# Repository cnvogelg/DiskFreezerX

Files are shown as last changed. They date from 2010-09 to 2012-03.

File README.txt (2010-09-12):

The DiskFreezerX Project
------------------------

Introduction
------------

The DiskFreezerX is a tool suite that allows to capture bit cell exact
information from a floppy disk. This approach samples disk information at the
lowest possible level and therefore preserves as much information as possible.

This project is heavily inspired by the ideas presented in the Cyclone 20 [1]
and KryoFlux [2] projects. We share the hardware platform (AT91SAM7x) for
connecting the disk drive and doing the low level sampling of the disk data.
However, all the software in this project was written from scratch.
Furthermore, the host hardware in DiskFreezerX is a beagle board that is
connected via SPI to the AT91SAM7x and not a PC connected via USB.

The goal of the DiskFreezerX project is to provide a modular tool set for
sampling disk information in a versatile way. We want to provide a full open
source solution to exact bit cell level disk archiving that supports lots of
platforms and devices. We start of with a working sample system running on a
beagle board and a SAM7x board and hope to add new supported HW platforms in
the near future.

Currently, the project is in no way an end user project, i.e. you cannot
simply buy some HW and off you go. It is rather a hacker project for you
technically skilled folks out there that know how to handle the HW stuff
described here... So you have been warned ;)

And now have fun!

Chris Vogelgsang aka. lallafa
<chris@vogelgsang.org>

[1] http://eab.abime.net/showthread.php?t=40959
    https://docs.google.com/Doc?id=dgddtc7_102gbzr2mgr&hl=en
[2] http://www.kryoflux.com/

Overview
--------

A DiskFreezerX system consists of the following components:

* A _Sampler_ is a hardware device that connects to the floppy drive, controls
  the floppy and samples the disk information. The sampling process is very
  time critical and therefore has a direct bare-metal implementation on a
  microcontroller. The sampled data contains large amounts of information and
  therefore. The "dfx-sampler" is the firmware running on a sampler. 

* A _Capture_ program that runs on a host system and is connected to the
  Sampler device. It does control the floppy drive (enable motor, step track,
  ...) and receives the bit cells sampled from the sampler. The capture
  program "dfx-capture" stores the sampled tracks for further processing

* _Anaylzer_ programs read the captured data and do the reconstruction of the
  bit information stored on disk and then the high level structures found
  there, e.g. disk formats of operating systems. As a result of analysis you
  either get lots information about the data found on the disk or you can
  directly derive disk images that can be used in emulators. The analyzers
  are currently written in Python and called with "dfx-analyzer".

Current System
--------------

The current reference platform consists of the following components:

* The Sampler is a AT91SAM7x board that directly connects to the floppy drive.
  The dfx-sampler firmware running there is written in C using only bare-metal
  (i.e. register) access to the device. The communication with the capture
  host is done via an SPI link. The SPI link runs at 3 MBit/s and the sampler
  is the slave device. Both the control commands and the sampled track data
  are transferred along this link.

* The capture host is a Beagle Board clone called IGEP v2 [3]. This board has
  an OMAP3 Cortex A8 ARM processor at 720 MHz and runs Poky Linux [4]. The
  board has an extension connector that provides an SPI channel. With a level
  converter attached (1.8V to 3.3V) the SPI can be directly connected to the
  SAM7x board. The dfx-capture software is written for the Linux spidev
  user-level SPI programming interface and requires a patched Linux kernel
  that enables the SPI device on the external connector. The capture software
  currently writes sampled raw tracks to one file per track. A disk is sampled
  as a directory of raw track files.

* The analyzer software is written in Python and runs on any system with a
  Python interpreter available. The analyzer handles single raw tracks and
  decodes them into blocks found on this track. A disk image is currently
  build by concatenating track blocks together. In future the anaylzer
  software will be extended into a Python class library with lots of helper
  classes for doing track analysis.

[3] http://www.igep-platform.com/index.php?option=com_content&view=article&id=46&Itemid=55
[4] http://labs.igep.es/index.php/How_to_setup_a_development_environment

Getting Started
---------------

More documentation of this project is located in the "doc" directory.
You'll find there:

EOF

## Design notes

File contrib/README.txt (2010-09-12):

igep_v2_spi_patch-2.6.33.6.diff

  This patch has to be applied to the IGEP v2 Kernel 2.6.33.6
  available at http://git.igep.es/?p=pub/scm/linux-omap-2.6.git;a=summary

  Have a look at
  http://labs.igep.es/index.php/Getting_started_with_IGEP_v2_board
  for more information about how to setup an own kernel for the board.

EOF

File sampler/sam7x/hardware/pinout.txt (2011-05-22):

DiskFreezerX SAM7x256 Pinout
----------------------------

PA0   OUT   floppy: WRITE DATA         (FD 22)
PA1   IN    floppy: WRITE_PROTECT      (FD 28)
PA2   OUT   floppy: DENSITY SEL        (FD  2)
PA3   OUT   SPI: WIZNET /CS
PA4   OUT   SPI: RTC /CS
PA5   OUT   SPIRAM: A0
PA6   OUT   SPIRAM: A1
PA7   OUT   SPIRAM: A2
PA8   OUT   SPIRAM: /CS
PA9   IN    floppy: TRACK 0            (FD  9)
PA10  OUT   floppy: SELECT 0           (FD 14)
PA11  OUT   SD CARD: /CS
PA12  IN    SPI: MISO
PA13  OUT   SPI: MOSI
PA14  OUT   SPI: CLK
PA15  IN    SD CARD: CARD DETECT

PA16  OUT   (EXTRA /CS)
PA17  OUT   LED 1
PA18  OUT   LED 2
PA19  OUT   floppy: MOTOR 0            (FD 10)
PA20  IN    WIZNET /IRQ
PA21  IN    RXD1 (Serial)
PA22  OUT   TXD1 (Serial)
PA23  IN    BUTTON 1
PA24  IN    BUTTON 2
PA25  IN    SD CARD: WRITE PROTECT
PA26  IN    floppy: READ DATA          (FD 30)
PA27  OUT   floppy: DIR SELECT         (FD 18)
PA28  OUT   floppy: TRACK STEP         (FD 20)
PA29  OUT   floppy: SIDE SELECT        (FD 32)
PA30  IN    floppy: INDEX              (FD  8)
PA31  OUT   floppy: WRITE GATE         (FD 24)

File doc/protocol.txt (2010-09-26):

The sampler Protocol
--------------------

The sampler is a stand-alone device performing the disk sampling and is
controlled via the capture tool running on a host system.

Sampler and capture tool communicate with a protocol to perform the disk
control and the sample data transfer.

This document describes the protocol and the data transfer mechanism.

Currently the protocol is implemented on an SPI link, but it is designed to
run on numerous different data transport mechanisms.

1. Command Protocol
-------------------

The sampler device starts in command mode after power up.
The command mode is only left while transferring sampled data.
The sampler then waits for a command line to be executed.

Main loop:

* The capture tool sends a command line. 

* The sampler executes the comands and returns a status line containing the
  results of all commands.

* The result values are one or more hex bytes that are returned in ASCII
  notation (2 chars per byte in hex).

  Each command has a single result byte assigned with the following meaning:
    0x80: command aborted execution
    0x40: command failed
    0x3f: mask for size n. n bytes follow on status line
  
* For each command the number of returned bytes is specified in the following list.

* Some commands also take parameters. Those are given as hex numbers, too.

Example:

  send commands:  "aX05"  <- send command "a" and "X" with argument "05"
  returns status: "014200" <- result "a" : 01 -> one extra byte "42"
                              result "X" : 00 -> ok, no extra byte

Commands
--------

  Floppy select
  
    e           select floppy
    d           disable floppy
    
  Motor control:
  
    o           motor on
    f           motor off
    s           seek to track zero
    + <xx>      step to forward <xx> tracks
    - <xx>      step to backwar <xx> tracks
    z           is track zero?
    
  Side select:
  
    t           top side
    b           bottom side
  
  Misc:    
    
    x           leave program

  Options:

    i <xx>      read up to <xx> index markers per track, i.e. rotations

    j           return index lengths
	r			read status
					u32		index_overruns
					u32		cell overruns
					u32		cell overflows
					u32		data size
					u32		data overflows

  Test Routines:

	I			measure index markers
	D			count data samples
	S			dump spectrum of data samples

2. SPI Implementation
---------------------

The SPI is designed so that the capture host is the SPI master and the sampler
board the SPI slave.

A Byte is written and clocked by the master while another one is read from the sampler.

2.1 Command Transfer

The following commands are defined for the master:

#define CMD_NONE        0x00
#define CMD_TX          0x01
#define CMD_RX          0x02

If CMD_NONE is written then this byte is simply ignored by the sampler.

A CMD_TX initiates a command line transfer to the sampler.
It is followed by a size byte and the n bytes of the command line.

A CMD_RX initiates a status line transfer from the sampler.
It is followed by a size byte. Then n  bytes are read from the sampler.

The Sampler signals its processing state by sending one of the following:

#define READY_MASK      0xc0
#define READY_FLAG      0x80
#define SIZE_MASK       0x3f

If the sampler is ready to receive and execute commands then the READY_FLAG is set.
(Highest bits are 0b10......)
If the sampler has some status bytes available this size is ORed into this flag.
At most 0x3f result bytes are allowed.

It the sampler is busy then the READY_FLAG is cleared until the command is executed.

A SPI command transfer works as follows:

  Wait for ready

  1.   Master: read 2 bytes                  Slave: send READY_FLAG, size=0 (0x80)
  2.   If bytes[1] != READY_FLAG goto 1
  
  Send Command Line to Sampler

  3.   Master: send CMD_TX + size + n bytes  Slave: receive n bytes 
                                                    clear READY_FLAG
                                                    process command and fill status buffer
  
  Wait for Command Finish

  4.   Master: read 2 bytes                         ...
  5.   If bytes[1] != READY_FLAG goto 4             ready, set READY_FLAG + status_size
       Optional: Handle Timeout if command
         takes too long

  Retrieve Command Status Line from Sampler

  6.   status_size = bytes[1] & SIZE_MASK
  7.   Master: send CMD_RX + status_size     Slave: handle CMD_RX 
       Master: receive status_size bytes            send n status bytes
                                                    reset status buffer
  8.   check status line. execution done

NB: The 2 bytes read for the master is only done as a single byte read seems to
have problems on the BeagleBoard SPI. On other implementations a single byte
read is fully sufficient.

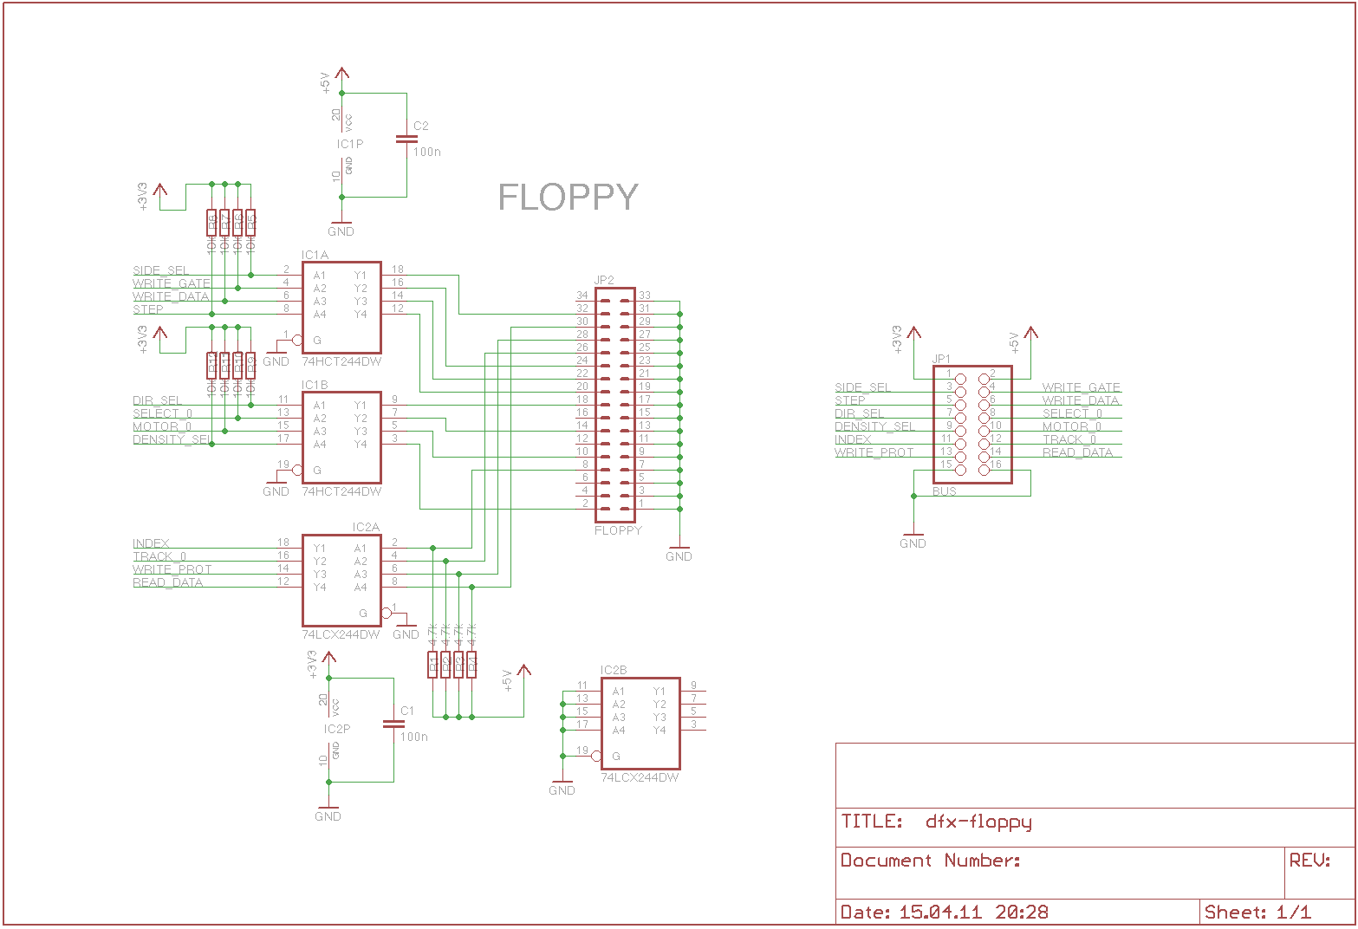
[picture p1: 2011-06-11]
sampler/sam7x/hardware/dfx-floppy-sch.png

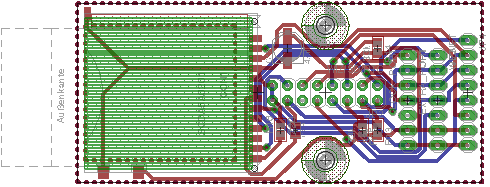
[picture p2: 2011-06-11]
sampler/sam7x/hardware/dfx-io-brd.png

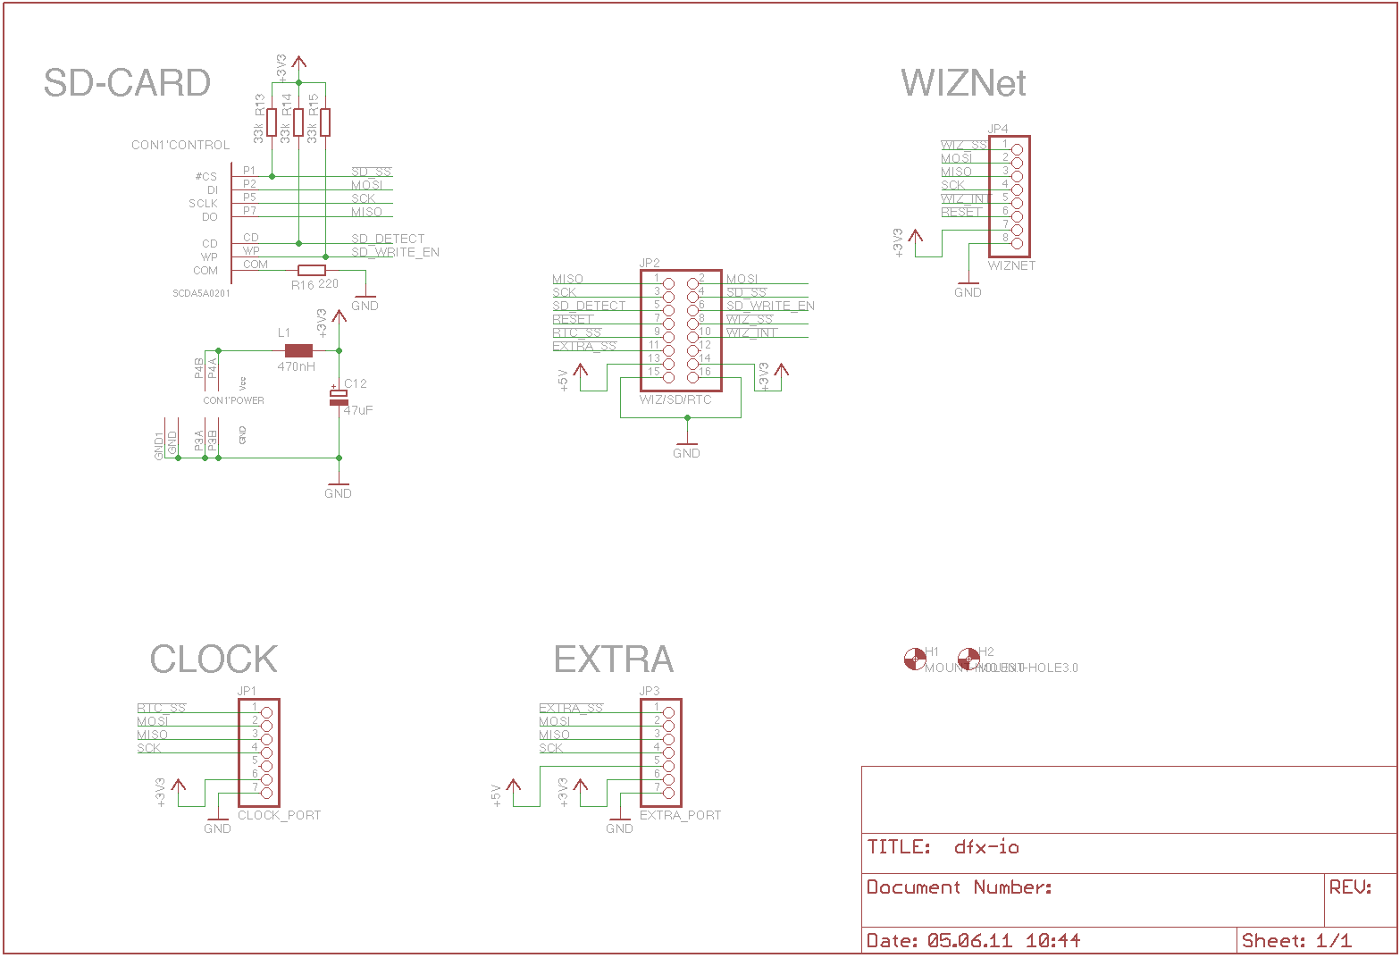
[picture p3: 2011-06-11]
sampler/sam7x/hardware/dfx-io-sch.png

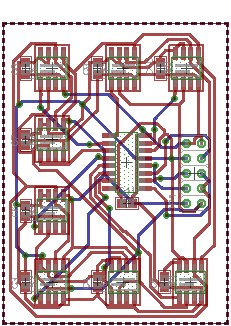
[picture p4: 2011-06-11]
sampler/sam7x/hardware/dfx-mem-brd.png

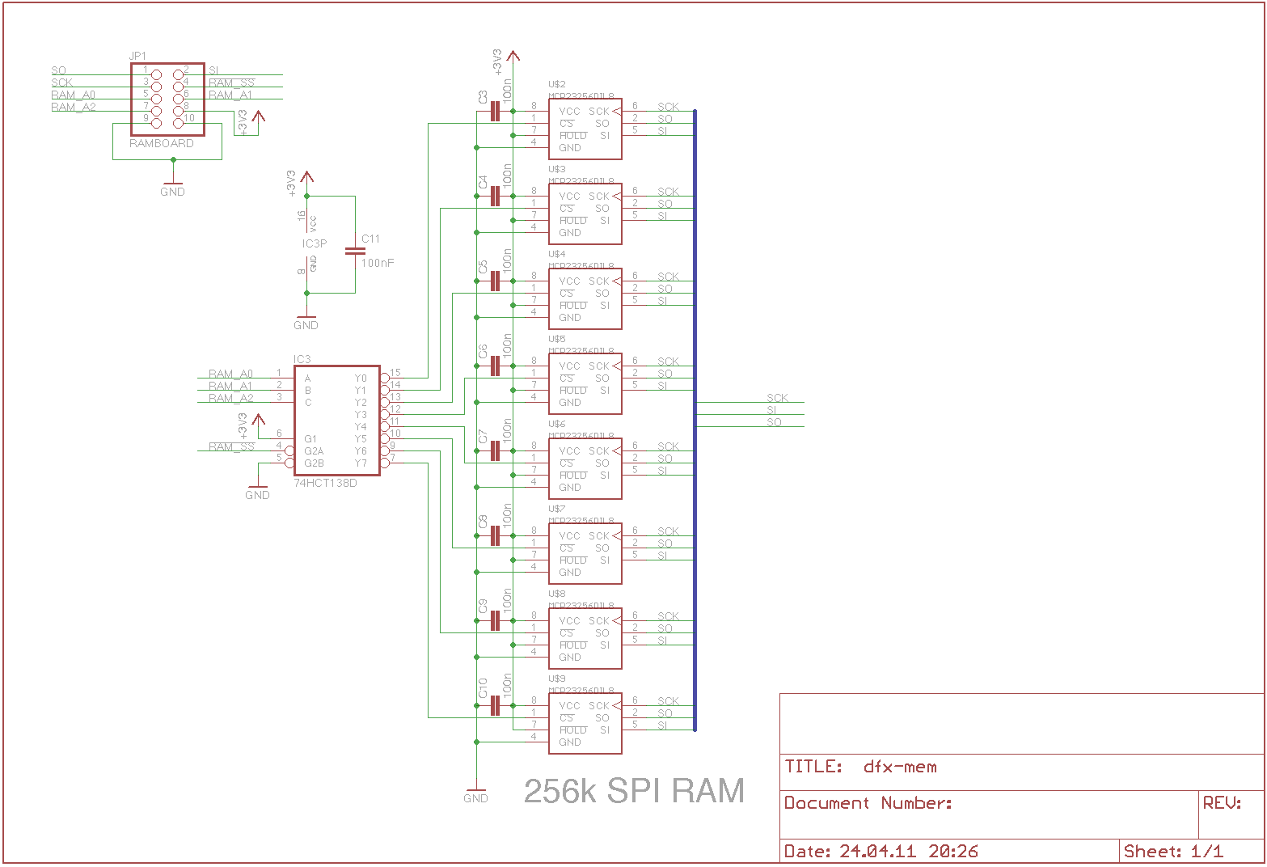
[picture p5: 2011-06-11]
sampler/sam7x/hardware/dfx-mem-sch.png

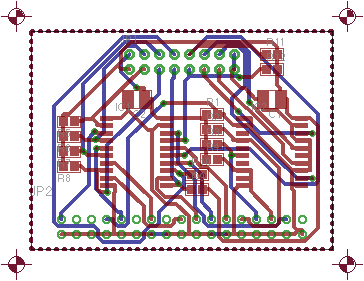
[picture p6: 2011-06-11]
sampler/sam7x/hardware/dfx-floppy-brd.png

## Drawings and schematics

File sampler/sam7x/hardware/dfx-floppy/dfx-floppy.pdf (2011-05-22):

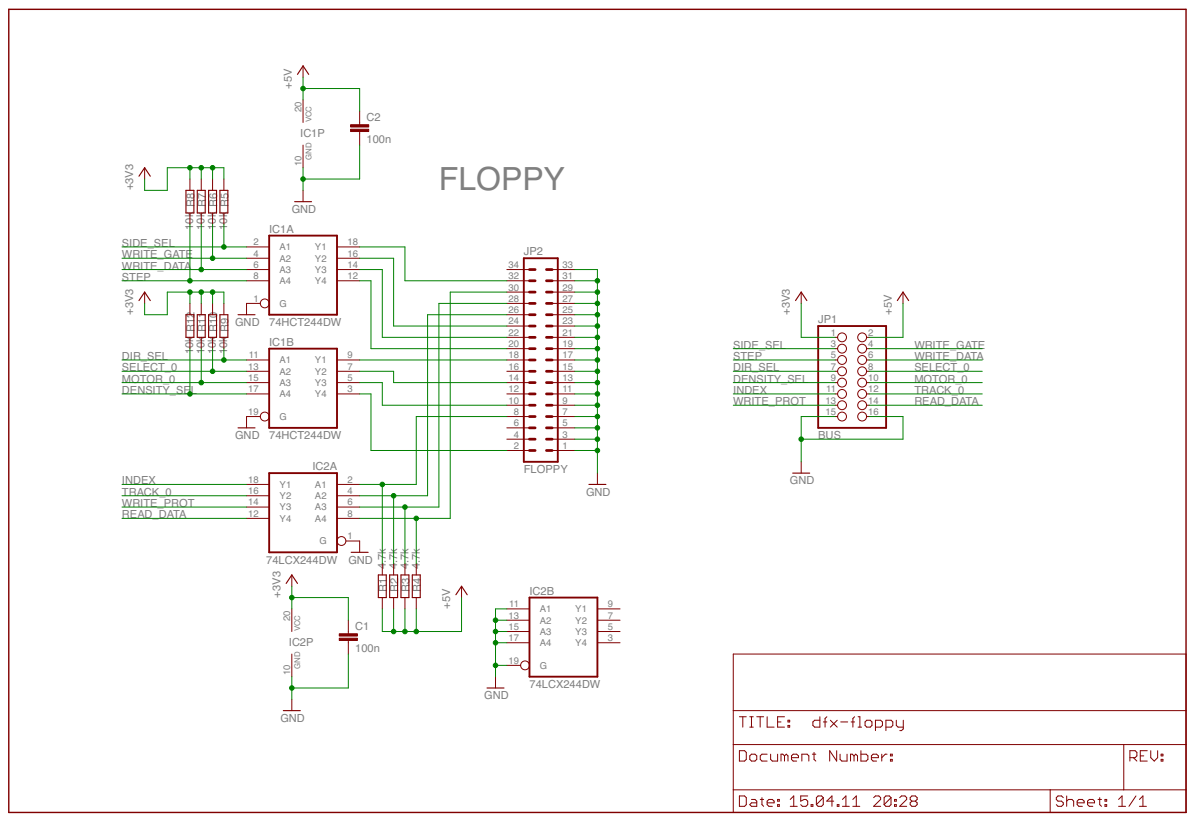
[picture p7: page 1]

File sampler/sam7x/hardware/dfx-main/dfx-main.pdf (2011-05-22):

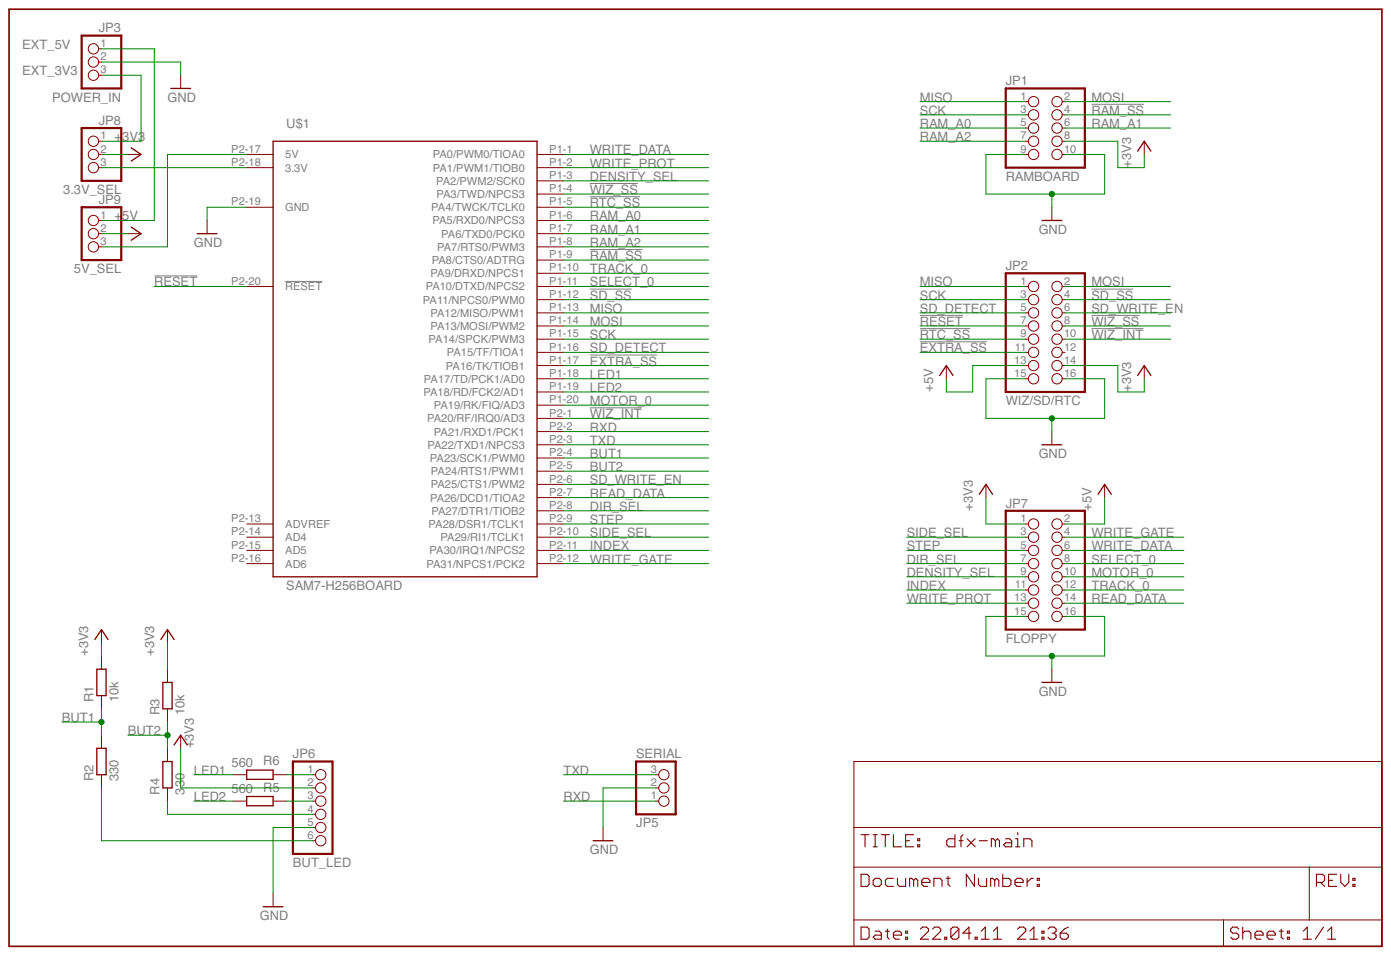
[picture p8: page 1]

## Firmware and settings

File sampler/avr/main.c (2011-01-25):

/*
 * main.c - main loop
 *
 * Written by
 *  Christian Vogelgsang <chris@vogelgsang.org>
 *
 * This file is part of dtv2ser.
 * See README for copyright notice.
 *
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
 */

#include "global.h"
#include "uart.h"
#include "timer.h"
#include "display.h"
#include "console.h"
#include "fat/fatfs.h"

static void read_image(void)
{
	FIL fsrc;
	FRESULT res;
	char filename[] = "main.raw";

	res = f_open(&fsrc, filename, FA_OPEN_EXISTING | FA_READ);
	if(res != FR_OK)
	{
		console_puts((u08 *)"file not found!");
	    return;
	}

	for(u08 y=0;y<240;y++) {
		for(u16 x=0;x<320;x++) {
			u08 rgb[3];
			UINT read;
			res = f_read(&fsrc, &rgb, 3, &read);
			if(res != FR_OK)
				break;

			u16 color = RGB(rgb[0],rgb[1],rgb[2]);

			display_set_area(x,y,x,y);
			display_draw_start();
			display_draw_pixel(color);
			display_draw_stop();
		}
	}

	f_close(&fsrc);
}

int main (void){
  // board init. e.g. switch off watchdog
  board_init();  
  // setup timer
  timer_init();
  // setup serial
  uart_init();

  // display init()
  display_init(2);
  console_init();
  console_puts((const u08 *)"AVRcon:\n");

  // sdcard/fatfs init
  fatfs_init(2);
  console_puts((const u08 *)"fatfs init\n");

  // mount sdcard
  if(fatfs_mount() == 0)
  {
	  console_puts((const u08 *)"mounted!");

	  read_image();

	  fatfs_umount();
  }
  else
  {
	  console_puts((const u08 *)"no card!");
  }

  // main loop
  while(1) {
      u08 ch = uart_read();
      console_putch(ch);
  }
  return 0;
}

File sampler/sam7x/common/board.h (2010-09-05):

/*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
* Creation            : JPP   16/Jun/2004
*  1.1 14/Oct/05 JPP  : Change MCK
*----------------------------------------------------------------------------
*/

/* Modifications by Martin Thomas for the WinARM example :
   - define __inline as static inline
   - ramfunc for GNU-tools (see linker-script)
   - modifications for multiple submodels (7S64 and 7S256)
   - added definitons for OX SAM7-P
*/

#ifndef Board_h
#define Board_h

//#define ATMEL_AT91SAM7S_EK
#define OX_SAM7_P

#define __inline static inline

#if defined(__WINARMSUBMDL_AT91SAM7S64__)
#include "AT91SAM7S64.h"
#include "lib_AT91SAM7S64.h"
#elif defined(__WINARMSUBMDL_AT91SAM7S256__)
#include "AT91SAM7S256.h"
#include "lib_AT91SAM7S256.h"
#else
#error "Submodel undefined"
#endif

#define __ramfunc __attribute__ ((long_call, section (".fastrun")))

#define true	-1
#define false	0

#define _BV(x)  (1<<x)

typedef unsigned int u32;
typedef unsigned short u16;
typedef unsigned char u08;

/*-------------------------------*/
/* SAM7Board Memories Definition */
/*-------------------------------*/
// The AT91SAM7S64  embeds a 16 kByte SRAM bank, and  64 kByte Flash
// The AT91SAM7S256 embeds a 64 kByte SRAM bank, and 256 kByte Flash

#define  INT_SRAM           0x00200000
#define  INT_SRAM_REMAP	    0x00000000

#define  INT_FLASH          0x00000000
#define  INT_FLASH_REMAP    0x00100000

#define  FLASH_PAGE_NB		AT91C_IFLASH_NB_OF_PAGES
#define  FLASH_PAGE_SIZE	AT91C_IFLASH_PAGE_SIZE

#if defined(ATMEL_AT91SAM7S_EK)
/*-----------------*/
/* LEDs Definition */
/*-----------------*/
/*                                 PIO   Flash    PA    PB   PIN */
#define LED1            (1<<0)	/* PA0 / PGMEN0 & PWM0 TIOA0  48 */
#define LED2            (1<<1)	/* PA1 / PGMEN1 & PWM1 TIOB0  47 */
#define LED3            (1<<2)	/* PA2          & PWM2 SCK0   44 */
#define LED4            (1<<3)	/* PA3          & TWD  NPCS3  43 */
#define NB_LED			4
#define LED_MASK        (LED1|LED2|LED3|LED4)

/*-------------------------*/
/* Push Buttons Definition */
/*-------------------------*/
/*                                 PIO    Flash    PA    PB   PIN */
#define SW1_MASK        (1<<19)	/* PA19 / PGMD7  & RK   FIQ     13 */
#define SW2_MASK        (1<<20)	/* PA20 / PGMD8  & RF   IRQ0    16 */
#define SW3_MASK        (1<<15)	/* PA15 / PGM3   & TF   TIOA1   20 */
#define SW4_MASK        (1<<14)	/* PA14 / PGMD2  & SPCK PWM3    21 */
#define NB_SW           4
#define SW_MASK         (SW1_MASK|SW2_MASK|SW3_MASK|SW4_MASK)

#define SW1 	(1<<19)	// PA19
#define SW2 	(1<<20)	// PA20
#define SW3 	(1<<15)	// PA15
#define SW4 	(1<<14)	// PA14

#elif defined(OX_SAM7_P)
/* LEDs */
#define LED1            (1<<18)	/* PA18 */
#define LED2            (1<<17)	/* PA17 */
#define NB_LED			2
#define LED_MASK        (LED1|LED2)
/* Buttons */
#define SW1_MASK        (1<<19)	/* PA19 / PGMD7  & RK   FIQ     13 */
#define SW2_MASK        (1<<20)	/* PA20 / PGMD8  & RF   IRQ0    16 */
#define NB_SW           2
#define SW_MASK         (SW1_MASK|SW2_MASK)
#define SW1 	(1<<19)	// PA19
#define SW2 	(1<<20)	// PA20

#else
#error "Unsupported board"
#endif

/*------------------*/
/* USART Definition */
/*------------------*/
/* SUB-D 9 points J3 DBGU */
#define DBGU_RXD		AT91C_PA9_DRXD	  /* JP11 must be close */
#define DBGU_TXD		AT91C_PA10_DTXD	  /* JP12 must be close */
#define AT91C_DBGU_BAUD	   115200   // Baud rate

#define US_RXD_PIN		AT91C_PA5_RXD0    /* JP9 must be close */
#define US_TXD_PIN		AT91C_PA6_TXD0    /* JP7 must be close */
#define US_RTS_PIN		AT91C_PA7_RTS0    /* JP8 must be close */
#define US_CTS_PIN		AT91C_PA8_CTS0    /* JP6 must be close */

/*--------------*/
/* Master Clock */
/*--------------*/

#define EXT_OC          18432000   // Exetrnal ocilator MAINCK
#define MCK             48054857   // MCK (PLLRC div by 2)
#define MCKKHz          (MCK/1000) //

#endif /* Board_h */

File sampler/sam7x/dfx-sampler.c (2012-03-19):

#include "led.h"
#include "floppy-low.h"
#include "timer.h"
#include "util.h"
#include "diskio.h"
#include "sdpin.h"
#include "spi_low.h"

#include "uart.h"
#include "uartutil.h"

#include "cmd_parse.h"

#include "memory.h"
#include "floppy.h"
#include "track.h"
#include "rtc.h"
#include "net.h"

int main(void)
{
    // board setup stuff
    led_init();
    uart_init();
    floppy_low_init();
    sdpin_init();
    spi_low_cs_init();
    spi_low_mst_init();
    //timer_init();

    // say hello
    uart_send_string((u08 *)"--- dfx-sampler sam7x/SPI ---");
    uart_send_crlf();

    // do initial setup
    rtc_init();
    memory_init();
    floppy_select_on();
    track_init();
    floppy_select_off();
    net_init();

    // print current RTC
    uart_send_string((u08 *)"rtc:  ");
    uart_send_string((u08 *)rtc_get_time_str());
    uart_send_crlf();

    // show network info
    net_info();

    while(1) {
        uart_send_string((u08 *)"> ");
        
        led_green(1);
        
        // get next command via SPI
        u08 *cmd;
        u08 len = cmd_uart_get_next(&cmd);

        led_green(0);
        
        if(len>0) {
            u08 result[CMD_MAX_SIZE];
            u08 res_size = CMD_MAX_SIZE;
            
            // parse and execute command
            cmd_parse(len, cmd, &res_size, result);
            
            // report result
            if(res_size > 0) {
                uart_send_data(result, res_size);
                uart_send_crlf();
            }
        }
    }
}

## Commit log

2010-09-05 initial commit of dfx
    [sam7x256.cfg]
2010-09-05 improved disk reading stability
    [dfx-droid.c, spi.c]
2010-09-12 cleaned up track reder and removed index irq
2010-09-12 moved droid to sampler
    [sam7x256.cfg]
2010-09-12 added docs. improved command interface
    [sam7x256.cfg]
2010-09-25 added SAM-BA bootloader support to dfx-sampler on sam7x
2010-09-26 added status reporting to sampler. check status in capture.
2010-11-04 switched index handling to ext IRQ1 and PIT
2011-01-14 added uart rx buffering
2011-01-23 added DMA to spi ram access
2011-02-05 added multi spi ram support
2011-02-05 fixed read track to ram
    [cmd_parse.c, uartutil.c]
2011-02-05 fixed timing issues by switching back to ARM mode
2011-02-11 moved SD SPI to port 1
2011-02-11 Refactored SD Card pin handling
2011-02-11 more SPI clean up
2011-02-11 SPI clean up cont.
2011-02-11 introduced common SPI functions
2011-02-11 fixed SPI RAM transfers
2011-02-13 more cleanup in sd driver
2011-02-13 enabled long file name support fixed write protect detection started with file write
    [cmd_parse.c, diskio_spi.c, file.c]
2011-02-13 introduced own commands for spi channels
2011-02-13 added track read sim
2011-02-13 spi write fixes
2011-02-13 working towards track save
2011-02-27 improved sample core and added more markers
2011-03-03 added button control
2011-05-22 moved all io pin definitions to target.h
2011-05-22 added eagle files for hw modules: main, floppy
    [dfx-floppy.brd, dfx-floppy.sch, dfx-main.brd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]
2011-05-22 fixed button queries
2011-05-22 added led diagnose command
2011-05-22 track read commands always return number of indices
2011-05-22 fixed sd pin query
2011-05-22 added missing floppy write protect and density select
    [cmd_parse.c, floppy-low.c]
2011-06-02 added schematic for dfx-mem memory board
    [dfx-mem.brd, dfx-mem.sch]
2011-06-05 updated compiler. some sd pin fixes.
    [cmd_parse.c]
2011-06-05 added schematics/board for dfx-io module
    [dfx-io.brd, dfx-io.sch]
2011-06-11 added schematic/board pictures
2011-06-11 Cleaned up SPI constants
2012-03-18 swap ram in openocd init
    [sam7x256.cfg]
2012-03-18 use sample timer irq
2012-03-18 reverted track reader
2012-03-21 introduced global error codes
    [buffer.c, cmd_parse.c, disk.c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]

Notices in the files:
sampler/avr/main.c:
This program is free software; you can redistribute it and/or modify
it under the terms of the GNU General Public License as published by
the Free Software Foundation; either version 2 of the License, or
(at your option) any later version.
